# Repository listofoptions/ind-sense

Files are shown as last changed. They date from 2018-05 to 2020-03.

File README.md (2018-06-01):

# ind-sense
a prototype mechanical keyboard design based on inductive and capacitive sensing

project folder layout:
* cad        - contains the kicad and autocad files for pcb and switch design
* datasheets - information about the mechanical and electrical components used
* jupyter    - ipython notebook for the theory of operation 
* layout     - proposed eventual keyboard layouts
* scripts    - help scripts for use with design
* spice      - ltspice simulation source 

the main driving idea behind this keyboard switch design is to to build an even
more reliable beam spring like keyboard, that is a non conductivly sensed switch
with a high lifetime. the main mechanism of failure of most capacitive switches
is dirt and dust sensitivity, 
# ind-sense
a prototype mechanical keyboard design based on inductive and capacitive sensing

project folder layout:
* cad        - contains the kicad and autocad files for pcb and switch design
* datasheets - information about the mechanical and electrical components used
* jupyter    - ipython notebook for the theory of operation 
* layout     - proposed eventual keyboard layouts
* scripts    - help scripts for use with design
* spice      - ltspice simulation source 

the main driving idea behind this keyboard switch design is to to build an even
more reliable beam spring like keyboard, that is a non conductivly sensed switch
with a high lifetime. the main mechanism of failure of most capacitive switches
is dirt and dust sensitivity, which can be mitigated against by the use of a
spacer. This however makes the capacitive mechanism useless, (too much distance
at low voltages) to ensure the functionality of a such a mechanism I use an
inductive pad as the sensing element, such that when a peice of silicon steel
laminate is placed near the pad (with a protective spacer between!) the 
inductance, and hence the impedence of the circuit is changed. this of couse can
be sensed by the controller.

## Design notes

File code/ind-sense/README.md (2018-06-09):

this is the source code for the ind-sense controller, it generates the 
controller c-code that gets compiled via the arduino ide, and transfered to the
controller.

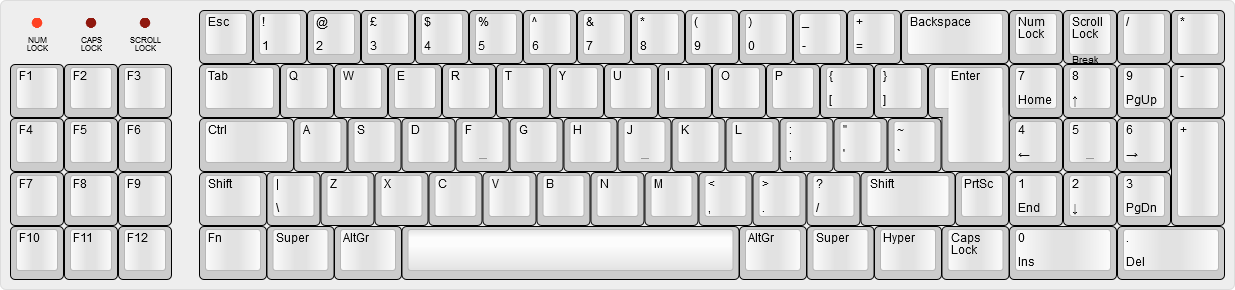
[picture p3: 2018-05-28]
layout/new xt.png

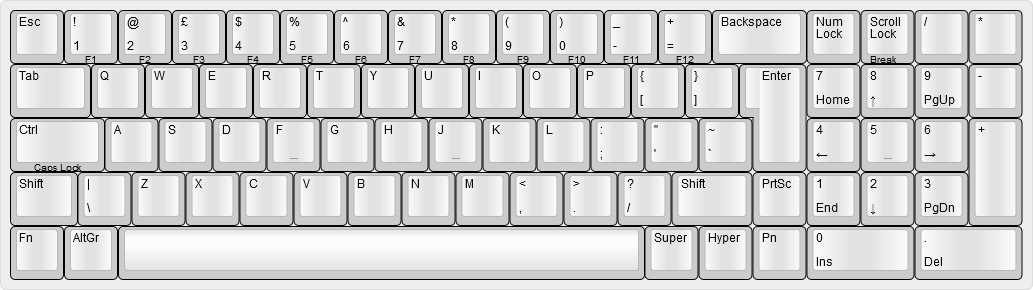
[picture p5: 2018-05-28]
layout/mini xt 9.75u.png

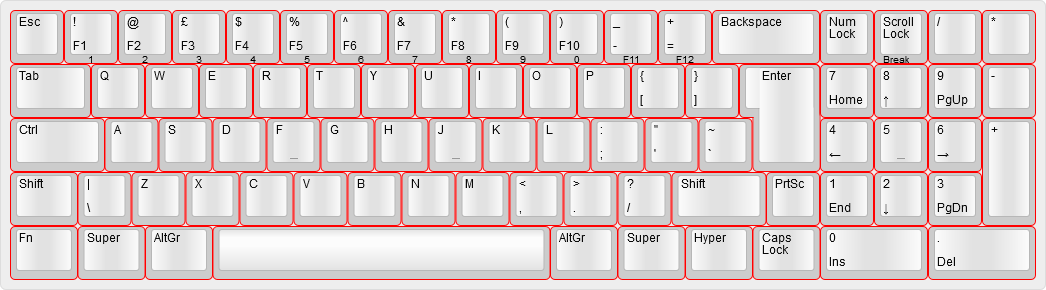
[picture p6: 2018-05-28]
layout/mini xt.png

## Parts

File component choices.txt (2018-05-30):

geometric contraining equation for the number of turns usable by a given
inductor
n_g = floor(((d_out - 1/2*w) - (d_in + 1/2*w))/(2*(w + s)))

input offset voltage of the cmp04 is 1mv, this limits the minimum voltage 
differential for the inductor

current draw of each of the components used:
ATmega32u2:  0.050 mA
cmp04:       0.012 A
TPIC6B595:   0.050 A
mcp4821:     0.050 A
8x100k(ohm): 0.00005 A
---------------------
          = 0.163 A
fudge:    + 0.062 A
---------------------
          = 0.225 A
---------------------
max:      - 0.475 A
---------------------
          = 0.200 A  : free current for use in the keyswitch matrix
          
to limit current:
    5/0.025 = 200 Ohms
    0.025*8 = 200 mA

this means that a total of 25mA is available to each inductor
in simulation (with perfect components) to achive a net voltage differential of
at least 2mV a 4kHz frequency is needed, given a large enough induction upon.
switch closure. a custom firmware or another controller is needed

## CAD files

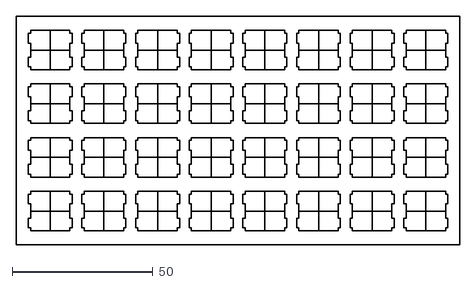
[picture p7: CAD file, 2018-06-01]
cad/autocad/macropad_1.dxf
157.4 x 81.2

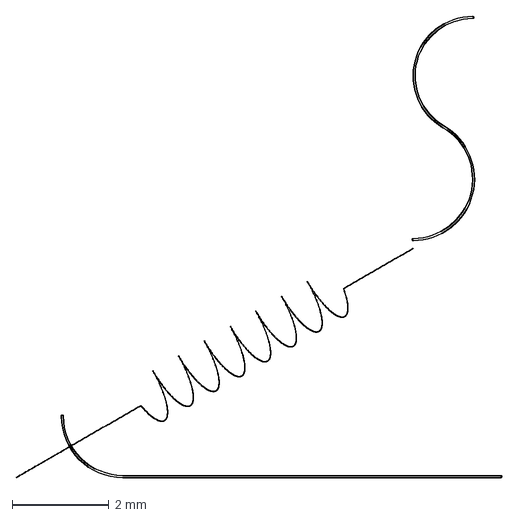
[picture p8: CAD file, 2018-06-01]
cad/autocad/logo.dxf
10.0 x 9.52 mm

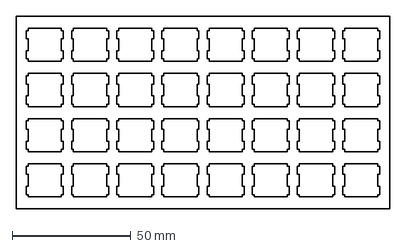
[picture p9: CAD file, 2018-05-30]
cad/autocad/macropad.dxf
157.4 x 81.2 mm

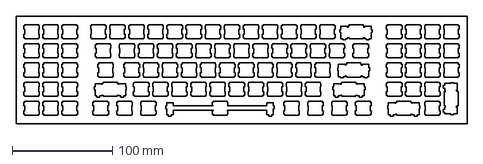
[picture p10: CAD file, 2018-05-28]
cad/autocad/keyboard_plate.dxf
450.1 x 107.2 mm

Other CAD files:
cad/autocad/pad_2.dwg
cad/autocad/pad.dwg
cad/autocad/case.dwg

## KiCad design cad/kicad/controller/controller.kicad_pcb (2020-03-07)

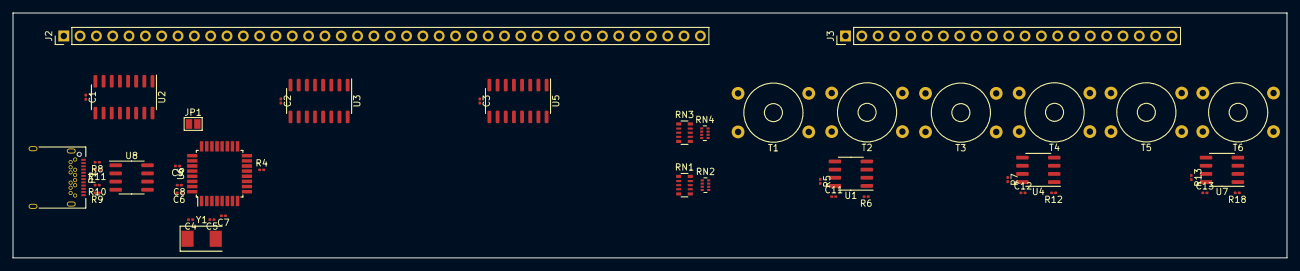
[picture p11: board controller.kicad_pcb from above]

Board: 2 copper layers, 198.2 x 38.1 mm, 46 parts (0 on the bottom side), 86 nets, no tracks yet.

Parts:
C1, C2, C3, C6, C7, C8, C11, C12, C13: 0U1; C_0201_0603Metric
C4, C5: 22P; C_0201_0603Metric
C9: 1U; C_0201_0603Metric
J2: COLUMNS; PinHeader_1x40_P2.54mm_Vertical
J3: ROW; PinHeader_1x21_P2.54mm_Vertical
JP1: RESET; SolderJumper-2_P1.3mm_Open_Pad1.0x1.5mm
P1: USB_C_Plug_USB2.0; USB_C_Receptacle_Amphenol_12401548E4-2A
R4, R5, R6, R7, R12, R13, R18: 10K; R_0201_0603Metric
R8, R9: 5K1; R_0201_0603Metric
R10, R11: 22; R_0201_0603Metric
RN1, RN3: R_Pack05; R_Array_Convex_5x0603
RN2, RN4: R_Pack04; R_Array_Concave_4x0402
T1, T2, T3, T4, T5, T6: Transformer_1P_1S; Transformer_Toroid_Horizontal_D9.0mm_Amidon-T30
U1, U4, U7: LM393; SOIC-8_3.9x4.9mm_P1.27mm
U2, U3, U5: 74HC595; SOIC-16_3.9x9.9mm_P1.27mm
U6: ATmega32U2-AU; TQFP-32_7x7mm_P0.8mm
U8: USB6B1; SOIC-8_3.9x4.9mm_P1.27mm
Y1: 16M; Crystal_SMD_0603-2Pin_6.0x3.5mm

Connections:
+5V: C1.1, C2.1, C3.1, C6.1, C7.1, C8.1, C11.1, C12.1, C13.1, P1.A4, P1.A9, P1.B4, P1.B9, R5.2, R6.2, R7.2, R12.2, R13.2, R18.2, U1.8, U2.16, U3.16, U4.8, U5.16, U6.4, U6.31, U6.32, U7.8, U8.1, U8.8
/CLOCK: U2.11, U3.11, U5.11, U6.15
/COL1: J2.3, U2.7
/COL2: J2.5, U2.6
/COL3: J2.6, U2.5
/COL4: J2.8, U2.4
/COL5: J2.9, U2.3
/COL6: J2.11, U2.2
/COL7: J2.12, U2.1
/COL8: J2.14, U2.15
/COL9: J2.15, U3.7
/COL10: J2.17, U3.6
/COL11: J2.18, U3.5
/COL12: J2.20, U3.4
/COL13: J2.21, U3.3
/COL14: J2.23, U3.2
/COL15: J2.24, U3.1
/COL16: J2.26, U3.15
/COL17: J2.27, U5.7
/COL18: J2.29, U5.6
/COL19: J2.30, U5.5
/COL20: J2.32, U5.4
/COL21: J2.33, U5.3
/COL22: J2.35, U5.2
/COL23: J2.36, U5.1
/COL24: J2.38, U5.15
/CROWREF: RN1.10, RN2.8, U1.2, U1.6, U4.2, U4.6, U7.2, U7.6
/CROWREFDAC1: RN1.1, U6.26
/CROWREFDAC2: RN1.2, U6.25
/CROWREFDAC3: RN1.3, U6.23
/CROWREFDAC4: RN1.4, U6.22
/D+: U6.29, U8.7
/D-: U6.30, U8.6
/LE: U2.12, U3.12, U5.12, U6.18
/OUT1: R18.1, U6.11, U7.1
/OUT2: R13.1, U6.10, U7.7
/OUT3: R12.1, U4.1, U6.9
/OUT4: R7.1, U4.7, U6.8
/OUT5: R6.1, U1.1, U6.7
/OUT6: R5.1, U1.7, U6.6
/ROW1: T1.3, U1.5
/ROW1+: J3.3, T1.2
/ROW1-: J3.4, T1.1
/ROW2: T2.3, U1.3
/ROW2+: J3.6, T2.2
/ROW2-: J3.7, T2.1
/ROW3: T3.3, U4.5
/ROW3+: J3.9, T3.2
/ROW3-: J3.10, T3.1
/ROW4: T4.3, U4.3
/ROW4+: J3.12, T4.2
/ROW4-: J3.13, T4.1
/ROW5: T5.3, U7.5
/ROW5+: J3.15, T5.2
/ROW5-: J3.16, T5.1
/ROW6: T6.3, U7.3
/ROW6+: J3.18, T6.2
/ROW6-: J3.19, T6.1
/SDI: U2.14, U6.16
/STAGE1: U2.9, U3.14
/STAGE2: U3.9, U5.14
/TROWREF: RN3.10, RN4.8, T1.4, T2.4, T3.4, T4.4, T5.4, T6.4
/TROWREFDAC1: RN3.1, U6.19
/TROWREFDAC2: RN3.2, U6.20
/TROWREFDAC3: RN3.3, U6.21
/TROWREFDAC4: RN3.4, U6.5
/X+: C5.1, U6.2, Y1.2
/X-: C4.2, U6.1, Y1.1
/~OE: U2.13, U3.13, U5.13, U6.14
GND: C1.2, C2.2, C3.2, C4.1, C5.2, C6.2, C7.2, C8.2, C9.2, C11.2, C12.2, C13.2, JP1.1, P1.A1, P1.A12, P1.B1, P1.B12, P1.S1, R4.2, R8.1, R9.1, U1.4, U2.8, U2.10, U3.8, U3.10, U4.4, U5.8, U5.10, U6.3, U6.28, U7.4, U8.4, U8.5
GNDREF: J2.1, J2.2, J2.4, J2.7, J2.10, J2.13, J2.16, J2.19, J2.22, J2.25, J2.28, J2.31, J2.34, J2.37, J2.39, J2.40, J3.1, J3.2, J3.5, J3.8, J3.11, J3.14, J3.17, J3.20, J3.21, RN1.5, RN3.5
unnamed: C9.1, U6.27
unnamed: JP1.2, U6.24
unnamed: P1.A5, R8.2
unnamed: P1.A6, R11.2
unnamed: P1.A7, R10.2
unnamed: P1.B5, R9.2
unnamed: R4.1, U6.13
unnamed: R10.1, U8.3
unnamed: R11.1, U8.2
unnamed: RN1.6, RN1.7, RN2.3
unnamed: RN1.8, RN2.6, RN2.7
unnamed: RN1.9, RN2.1
unnamed: RN3.6, RN3.7, RN4.3
unnamed: RN3.8, RN4.6, RN4.7
unnamed: RN3.9, RN4.1

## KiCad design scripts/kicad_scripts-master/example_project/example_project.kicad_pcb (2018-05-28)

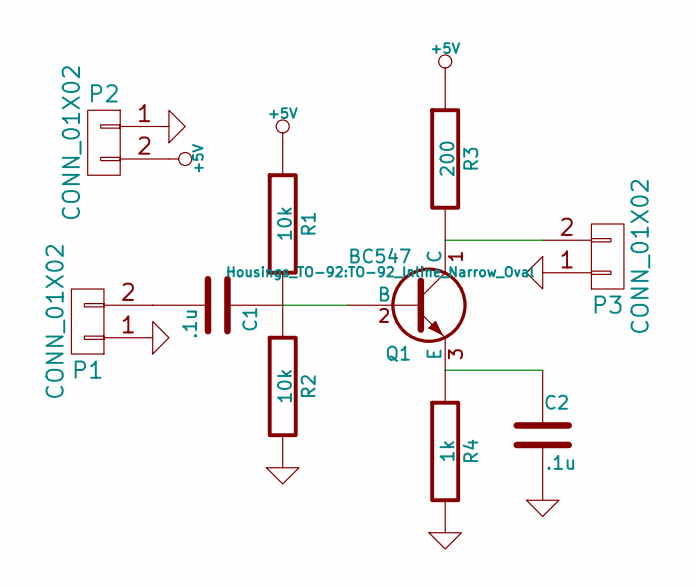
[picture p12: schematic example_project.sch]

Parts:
C1, C2: .1u; C_0805_HandSoldering
P1, P2, P3: CONN_01X02; Pin_Header_Angled_1x02
Q1: BC547; TO-92_Inline_Narrow_Oval
R1, R2: 10k; R_0805_HandSoldering
R3: 200; R_0805_HandSoldering
R4: 1k; R_0805_HandSoldering

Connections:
+5V: P2.2, R1.1, R3.1
GND: C2.2, P1.1, P2.1, P3.1, R2.2, R4.2
unnamed: C1.1, Q1.2 (B), R1.2, R2.1
unnamed: C1.2, P1.2
unnamed: C2.1, Q1.3 (E), R4.1
unnamed: P3.2, Q1.1 (C), R3.2

Board: 2 copper layers, 10 parts (0 on the bottom side), 6 nets, no tracks yet.

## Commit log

2018-05-30 updaded board and added some further documentation for egineering desicions, need to add further documentation to help people get up to speed with the project
    [ind-sense.kicad_pcb, ind-sense.sch, macropad.dxf]
2018-06-01 added logo, and started work on panelizing the demo pcb
    [ind-sense.kicad_pcb, ind-sense.sch, logo.dxf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]
2018-06-03 seperated the controller from the demo macropad, remade the controller to hopefully be less succeptable to emi, and digital interferance.
    [column.sch, ind-sense.kicad_pcb, ind-sense.sch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]
2018-06-09 updated controller with a lower part count equivalent, that should also be more accurate. need to have an actuall EE review the board and it's design
    [ind-sense.kicad_pcb, ind-sense.sch]
2018-06-10 worked on theory of operation spice, need to find a reliable equivalent circuit model, and a physical example of the pad
2020-03-07 in process redesign based on ADI/keytech induction board
    [controller.kicad_pcb, controller.sch, ind-sense.kicad_pcb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]
